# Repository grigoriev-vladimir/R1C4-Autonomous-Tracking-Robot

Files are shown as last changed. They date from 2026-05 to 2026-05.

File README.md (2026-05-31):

R1C4 - Autonomous Target Tracking Robot (Scale 3/5)

R1C4 is a 3/5 scale R2-D2 replica, co-developed as a duo with Emma Da Mota. It is equipped with computer vision to autonomously detect, track, and follow its "master" using a motorized turret system. This project combines computer vision, advanced mechatronics, and real-time control loops.

---

## 🎥 Demo
<table width="100%">
  <tr>
    <td width="50%" align="center">
      <p><b>Vision & Tracking (Jetson Nano)</b></p>
      <video src="https://github.com/user-attachments/assets/d546fa72-e5a3-4e6c-b071-dcd2d76cd6c8" width="100%" controls></video>
    </td>
    <td width="50%" align="center">
      <p><b>Comportement du Robot (Mechatronics)</b></p>
      <video src="https://github.com/user-attachments/assets/aad1944b-dfc9-40ba-a5d5-88d33bf9193e" width="100%" controls></video>
    </td>
  </tr>
</table>

---

## ✨ Key Features
* **Person Detection & Tracking:** Real-time human tracking using Computer Vision.
* **Active Turret Control:** Motorized dome/turret that smoothly pans to keep the target centered in the camera's field of view.
* **Custom Mechatronics:** Integrated power management, motor drivers, and 3/5 scale mechanical integration.

---

## 🛠️ Hardware Architecture
The robot architecture bridges high-level processing with low-level hardware actuation:

| Component Type | Model / Specification | Function |
| :--- | :--- | :--- |
| **Main Compute** | NVIDIA Jetson Nano | Runs the AI vision pipeline and processes the webcam feed |
| **Microcontroller** | ESP32 | Manages low-level motor control and timing |
| **Camera** |Logitech Webcam | Captures real-time video stream for tracking |
| **Turret Actuator** | Stepper Motor + TMC2209 | Drives the dome rotation smoothly and silently |
| **Wheel Actuator** | DC Motors + MDD10A SmartDrive | Controls the robot's main mobility and platform movement |
| **Power Supply** | External Power Bank / Battery | Provides independent power to the compute unit and motors |

---

## 🧠 Software & Control Logic

### 1. Vision & Recognition Pipeline
The high-level compute unit processes the webcam video feed frame-by-frame using a dual-stage approach:
* **Face Recognition (LBPH):** The system uses the **LBPH (Local Binary Patterns Histograms)** recognizer from OpenCV. It identifies the specific face of the "Master" based on a pre-trained dataset of face samples.
* **Target Tracking (CSRT):** Once the master is recognized, the system initializes an OpenCV **CSRT Tracker** on the target. This ensures robust, real-time tracking even with fast movements or partial occlusions.
* **Logic:** The Python script extracts the tracking bounding box center coordinates and calculates the horizontal pixel error relative to the camera's center view.

### 2. Communication & Control Loop
The tracking error is sent in real-time to the microcontroller to drive the robot's actuators:
* **Data Transmission:** The calculated pixel error is transmitted from the NVIDIA Jetson Nano to the **ESP32** via a **Serial (UART) link**.
* **Turret Actuation:** The ESP32 processes this error to command the **TMC2209** driver. It dynamically adjusts the stepper motor's speed and direction to smoothly and silently rotate the dome, keeping the master centered in the camera's field of view.
* **Mobility:** In parallel, the ESP32 handles the robot's displacement by driving the main DC motors through the **MDD10A** smart driver based on the system's operational state.
---

## 📁 Repository Structure
```text
├── src/
│   ├── vision/       # Python scripts for computer vision and target tracking
│   └── control/      # C++/Arduino firmware for motor control loops
├── hardware/
│   ├── electronics/  # Wiring diagrams and schematics
│   └── 3d-models/    # STL files for the custom turret mechanism
└── media/            # Images and GIFs for documentation

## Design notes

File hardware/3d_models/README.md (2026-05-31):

This folder contains the STL files for the custom parts of R1-C4 (dome mechanism, brackets, etc.)

Capture d'écran 2026-05-31 133051

## 🛠️ Bill of Materials (BOM) & Quantities

This section details the mechanical components and exact quantities required to build the robot assemblies, organized into three main modules.

### 🚗 1. Chassis Module (Requirements for 2 Full Chassis)
To manufacture **2 complete chassis**, the following mechanical parts are needed:
* **4x** Threaded rods (`R1C4-threaded_rod.step`) -> *4 threaded rods are strictly required to mount the wheels*
* **4x** Wheels (`R1C4-wheel.step`) -> *4 wheels are strictly required to assemble the chassis mechanism*
* **4x** Wheel covers with 13T pinion (`R1C4-wheel_cover_with_13t_pinion.step`)
* **2x** Chassis bases with motor (`R1C4-chassis_base_with_motor.step`)
* **2x** Chassis without motor (`R1C4-chassis_without_motor.step`)
* **2x** Motor pinions 22T (`R1C4-motor_pinion_22t.step`)
* **2x** Large support rods (`R1C4-arm_support_rod.step`)
* **6x** Mini rods (`R1C4-mini_rod.step`)
* **8x** Small nuts M12 (`R1C4-small_nut_m12_1_75.step`)
* **8x** Large nuts M12 (`R1C4-large_nut_m12_1_75_threaded_rod.step`)

---

### 🗼 2. Turret Module (Single Unit Requirements)
For the upper section and the tracking turret mechanism, only **1 unit** of each component is required:
* **1x** Dome / Capot (`R1C4-dome.step`)
* **1x** Turret skirt (`R1C4-turret_skirt.step`)
* **1x** Turret pinion (`R1C4-turret_pinion.step`)
* **1x** Motor pinion (`R1C4-motor_pinion_22t.step`)
* **1x** Top plate (`R1-C4 - Top.step`)
* **1x** Main Skirt (`R1-C4 - Skirt.step`)

---

### 🦴 3. Carcass Module (Structure & Frame - Single Unit Requirements)
All other structural components required to complete the main robot body (carcass) and internal mechanisms need **1 unit** each:
* **1x** R1-C4 - Chassis One Block.step
* **1x** Main Leg (`R1-C4 - Leg.step`)
* **1x** Ankle joint (`R1-C4 - Ankle.step`)
* **1x** Center foot axle (`R1-C4 - Axe center foot.step`)
* **1x** Elevator cage (`R1-C4 - Cage d'ascenseur V2.step`)
* **1x** Translation guide axle (`R1-C4 - Axe guide en translation.step`)
* **1x** Actuator support (`Support vérin V2.step`)
* **1x** Linear actuator lever arm (`R1C4-actuator_lever_arm.step`)
* **1x** Right wheel (`Roue droite.step`)
* **1x** Translation stop system (`R1-C4 - Arret en translation.step`)
* **1x** Upper translation stop bracket (`R1-C4 - Equerre arret translation haut.step`)
* **1x** Lower translation stop bracket (`R1-C4 - Equerre arret translation bas.step`)
* **1x** Motor support bracket (`R1-C4 - Equerre support moteur.step`)
* **1x** Translation guidance assembly (`R1-C4 - Assemblage guidage en translation...`)

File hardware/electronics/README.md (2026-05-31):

# ⚡ Electronics & Power Distribution

This folder contains the electrical architecture of R1-C4.

## 🗺️ Wiring Diagram

circuit diagram

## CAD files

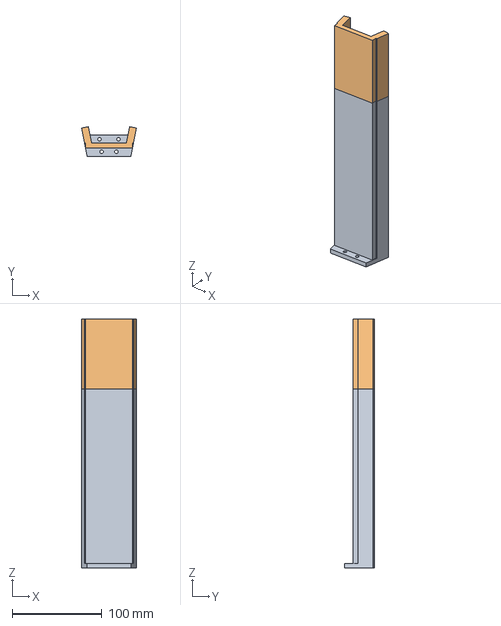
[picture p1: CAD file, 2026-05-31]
hardware/3d_models/R1-C4 - Assemblage guidage en translation front.step
61.2 x 33.0 x 278.0 mm

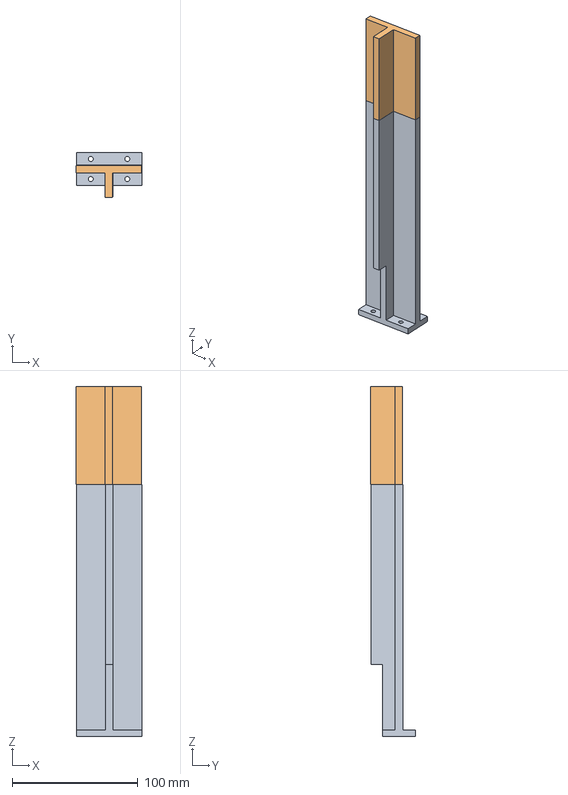
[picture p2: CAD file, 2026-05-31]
hardware/3d_models/R1C4-translation_guidance_assembly_02.step
52.1 x 35.5 x 278.0 mm

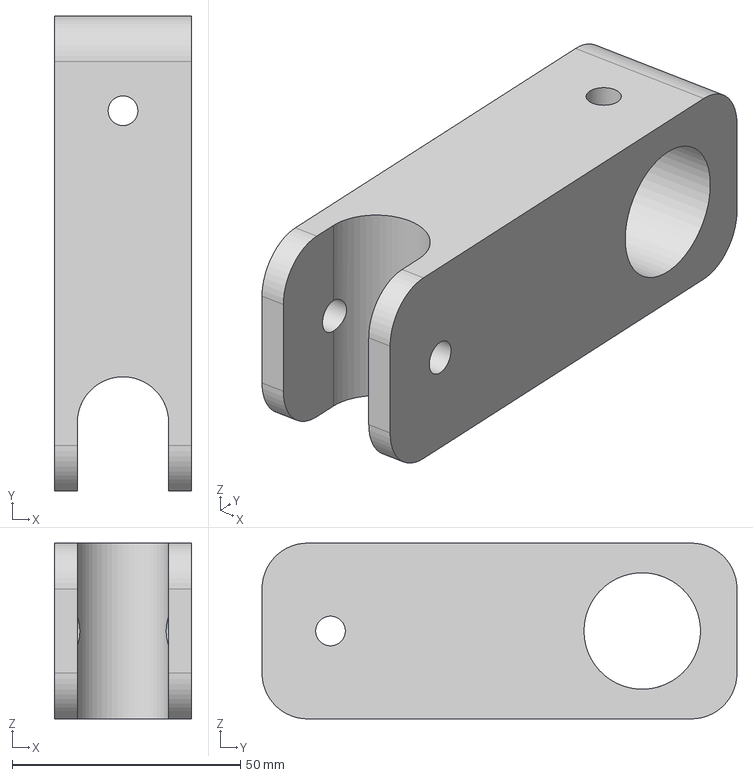
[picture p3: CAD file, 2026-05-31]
hardware/3d_models/R1C4-actuator_lever_arm.step
30.0 x 104.0 x 38.5 mm

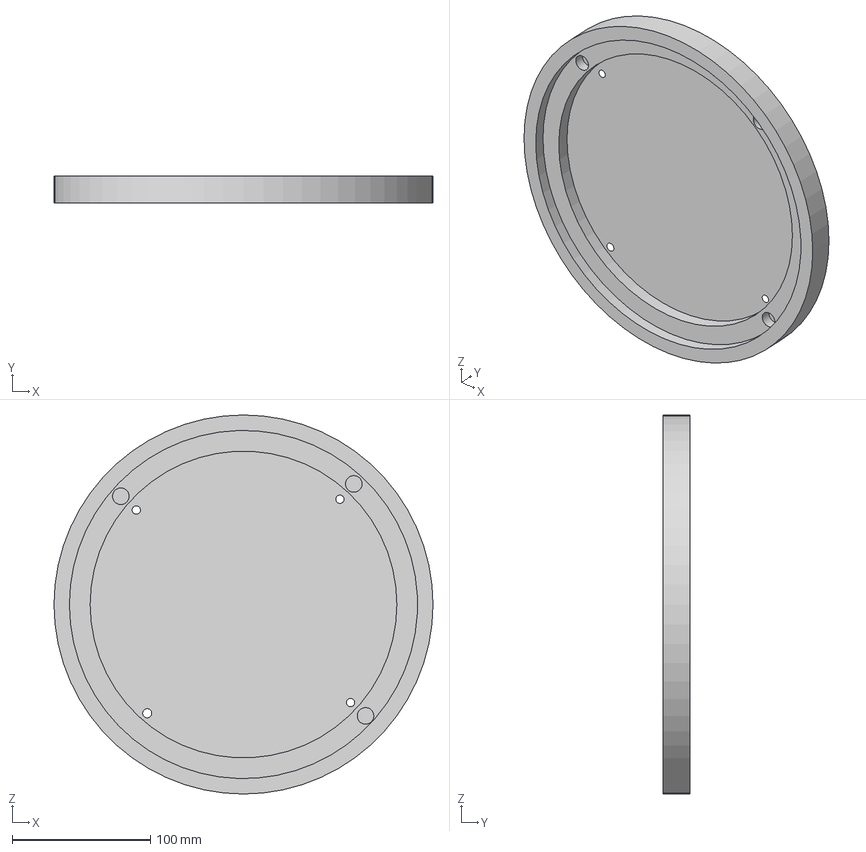
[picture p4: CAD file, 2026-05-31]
hardware/3d_models/R1C4-dome.step
274.3 x 19.8 x 274.3 mm

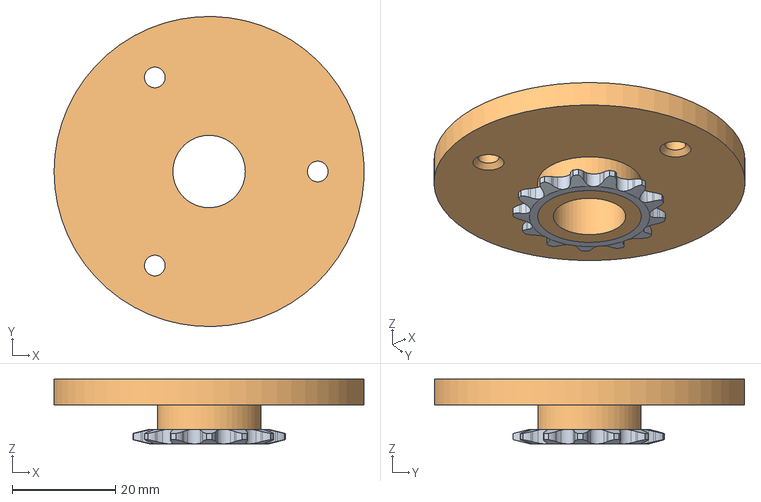
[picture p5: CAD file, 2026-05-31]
hardware/3d_models/R1C4-wheel_cover_with_13t_pinion.step
60.0 x 60.0 x 12.5 mm

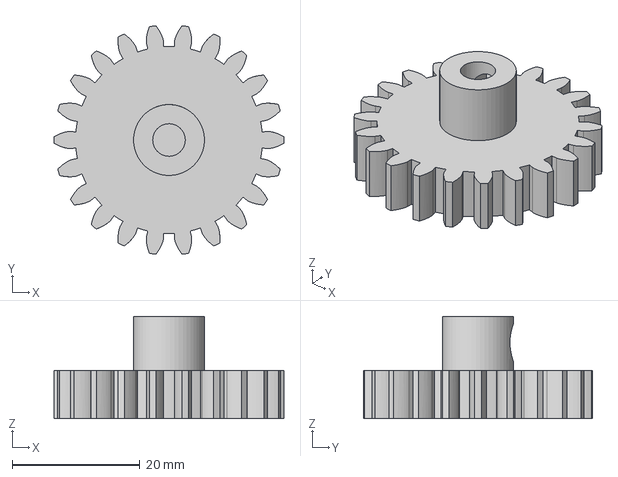
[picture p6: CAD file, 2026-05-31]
hardware/3d_models/R1C4-motor_pinion_22t.step
36.0 x 35.8 x 16.0 mm

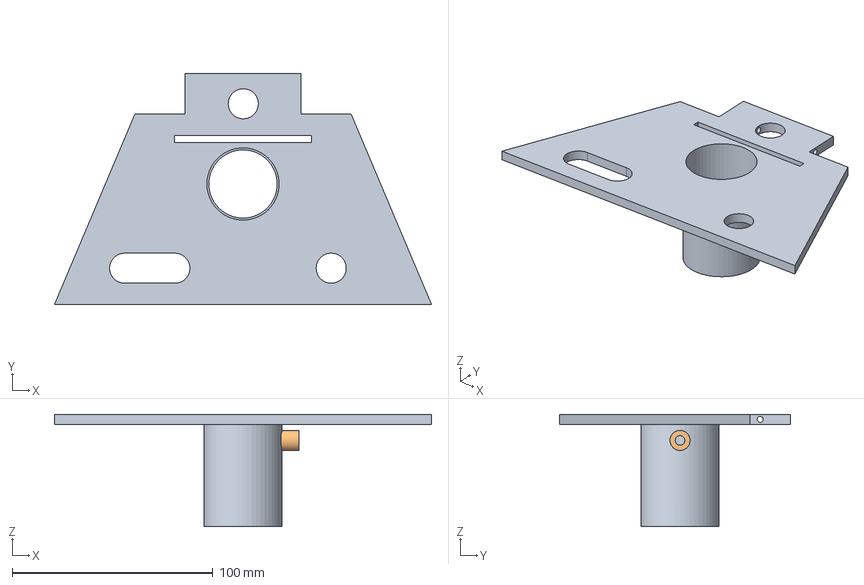
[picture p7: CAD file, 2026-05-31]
hardware/3d_models/R1C4-chassis_base_with_motor.step
188.0 x 115.0 x 56.0 mm

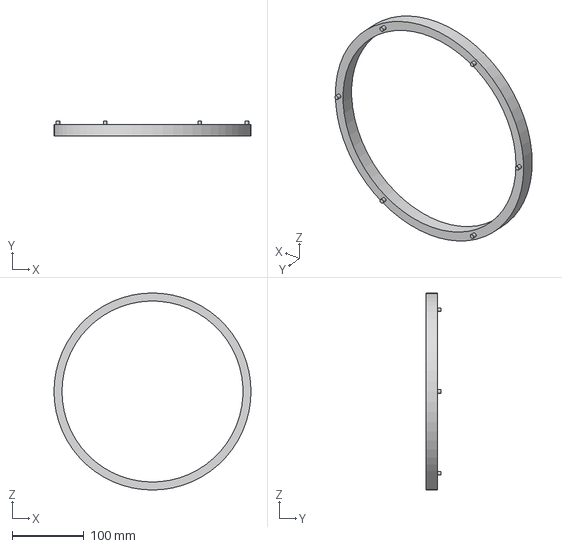
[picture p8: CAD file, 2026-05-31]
hardware/3d_models/R1C4-turret_skirt.step
274.3 x 21.0 x 274.3 mm

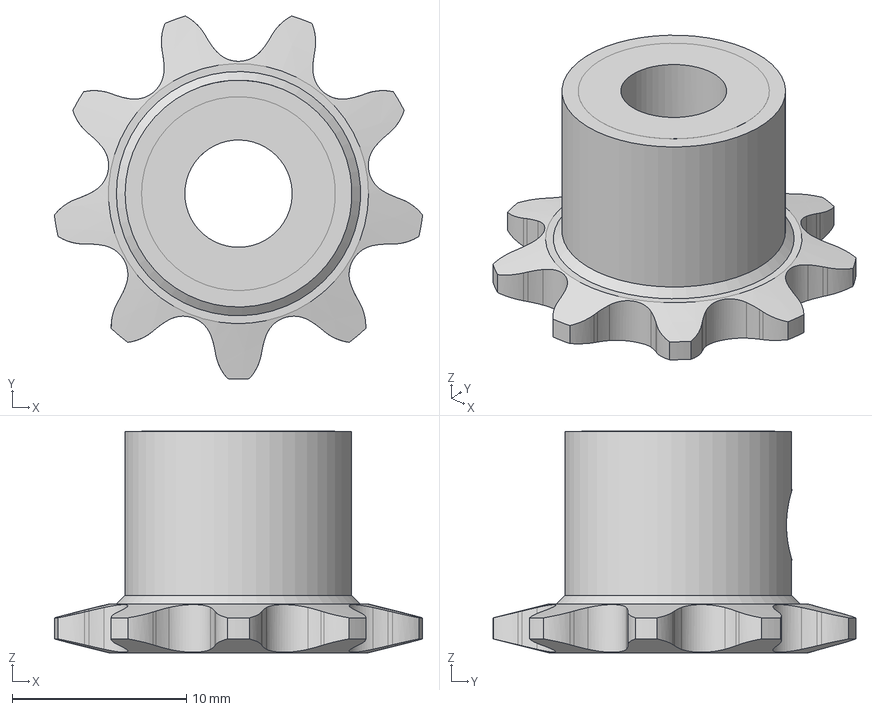
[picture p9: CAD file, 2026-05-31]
hardware/3d_models/R1C4-sprocket_9t_chain_25h_improved.step
21.1 x 20.8 x 12.7 mm

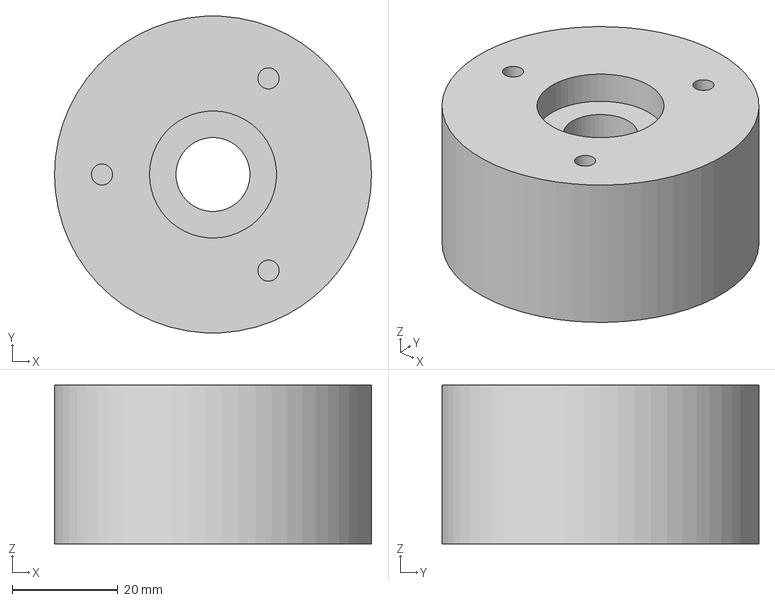
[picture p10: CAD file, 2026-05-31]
hardware/3d_models/R1C4-wheel.step
60.0 x 59.9 x 30.0 mm

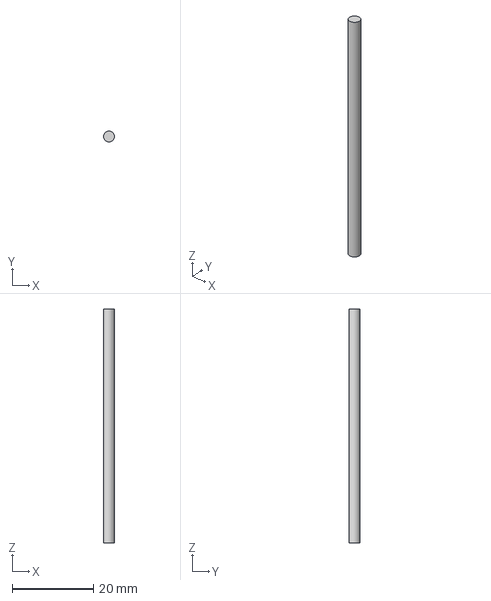
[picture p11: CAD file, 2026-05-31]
hardware/3d_models/R1C4-mini_rod.step
2.70 x 2.70 x 57.7 mm

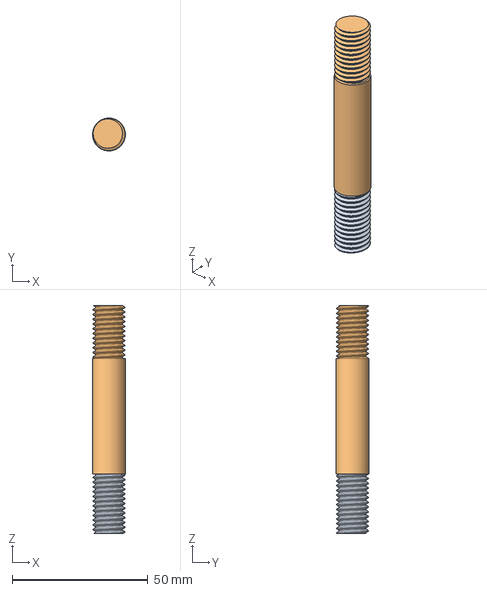
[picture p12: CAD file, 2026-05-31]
hardware/3d_models/R1C4-threaded_rod.step
12.1 x 12.1 x 84.1 mm

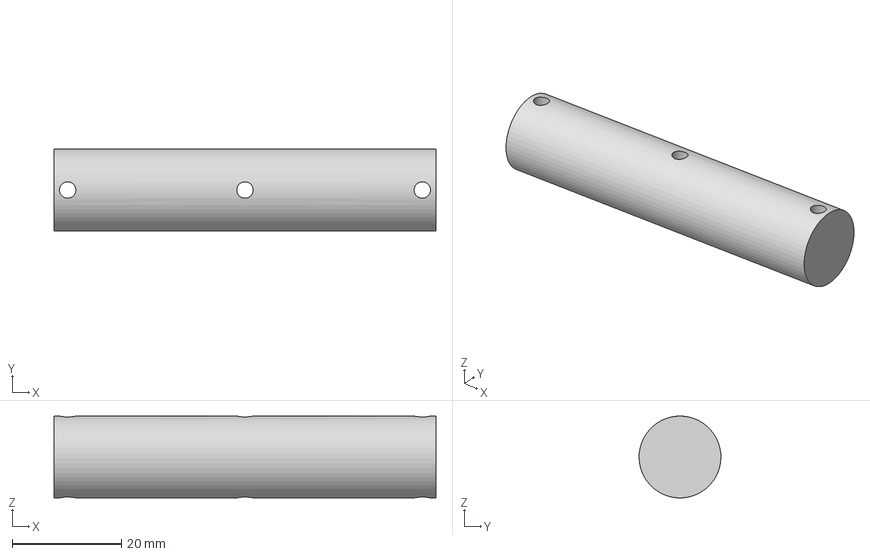
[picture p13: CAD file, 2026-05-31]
hardware/3d_models/R1C4-arm_support_rod.step
70.0 x 15.0 x 15.0 mm

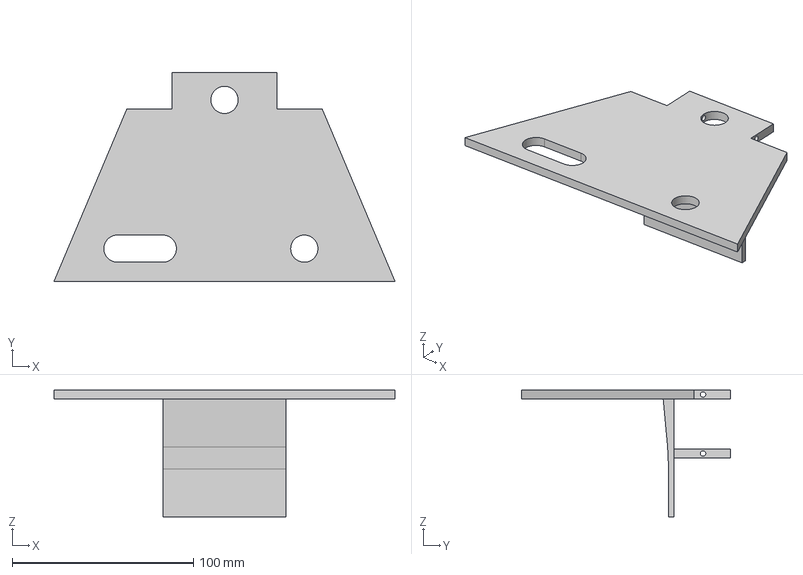
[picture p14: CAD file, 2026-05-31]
hardware/3d_models/R1C4-chassis_without_motor.step
188.0 x 115.0 x 70.0 mm

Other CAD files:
hardware/3d_models/R1-C4 - Equerre arret translation bas.step
hardware/3d_models/R1C4-translation_stop.step
hardware/3d_models/R1-C4 - Equerre support moteur.step
hardware/3d_models/R1-C4 - Equerre arret translation haut.step
hardware/3d_models/R1-C4 - Ankle.step
hardware/3d_models/R1-C4 - Axe center foot.step
hardware/3d_models/R1-C4 - Axe guide en translation.step
hardware/3d_models/R1-C4 - Cage d'ascenseur V2.step
hardware/3d_models/R1-C4 - Leg.step
hardware/3d_models/R1C4-large_nut_m12_1_75_threaded_rod.step
hardware/3d_models/R1C4-right_wheel.step
hardware/3d_models/R1C4-small_nut_m12_1_75.step

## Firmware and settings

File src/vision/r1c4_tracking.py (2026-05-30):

import json
import threading
import time
from pathlib import Path

import cv2
import numpy as np
import serial

# ══════════════════════════════════════════════════════════════════════════════
# ARRÊT PROPRE PAR "stop" DANS LE TERMINAL
# ══════════════════════════════════════════════════════════════════════════════
stop_event = threading.Event()

def _keyboard_listener():
    """Thread qui écoute le terminal : tape 'stop' + Entrée pour arrêter."""
    while not stop_event.is_set():
        try:
            line = input()
            if line.strip().lower() == "stop":
                print("Commande STOP reçue — arrêt en cours...")
                stop_event.set()
        except EOFError:
            break

_kb_thread = threading.Thread(target=_keyboard_listener, daemon=True)
_kb_thread.start()

# ══════════════════════════════════════════════════════════════════════════════
# CONFIGURATION
# ══════════════════════════════════════════════════════════════════════════════
PORT        = "COM3"        # ← votre port ESP32
BAUD        = 115200
SANS_SERIE  = False         # True = test sans ESP32

CAM_INDEX   = 1
# Résolution NATIVE de la caméra (avant rotation)
CAM_W       = 640
CAM_H       = 480
# Après rotation 90° : largeur et hauteur s'inversent
FRAME_W     = CAM_H        # = 480
FRAME_H     = CAM_W        # = 640

MODEL_PATH  = Path("lbph_model.yml")
LABELS_PATH = Path("labels.json")

FACE_SIZE   = (200, 200)
MIN_FACE    = (80, 80)
THRESHOLD   = 75.0        # distance LBPH max — ajustez selon vos distances
TRACK_FACE_THRESHOLD = 125.0   # plus tolérant pendant le suivi, utile profil/dos

# Tourelle
DEAD_ZONE_PX  = 50          # zone morte large → ignore les petits écarts
DEG_PER_PX    = 0.1        # gain très doux
MAX_ROT_DEG   = 15.0        # amplitude max réduite
ROT_PERIOD_S  = 0.25        # commande toutes les 250ms max

# Balayage recherche
SCAN_STEP_DEG  = 10
SCAN_LIMIT_DEG = 180
SCAN_PERIOD_S  = 1.8

# Tracker
TRACKER_LOST_LIMIT = 45

# Validation forme personne pour éviter de tracker le mur
MIN_PERSON_RATIO = 0.60   # hauteur / largeur minimale
MAX_PERSON_RATIO = 8.00   # hauteur / largeur maximale
MIN_BODY_AREA    = 1200   # surface min de la boîte


# ══════════════════════════════════════════════════════════════════════════════
# FILTRE DE KALMAN
# ══════════════════════════════════════════════════════════════════════════════
def make_kalman() -> cv2.KalmanFilter:
    kf = cv2.KalmanFilter(4, 2)
    dt = 1.0
    kf.transitionMatrix = np.array(
        [[1, 0, dt, 0],
         [0, 1,  0, dt],
         [0, 0,  1,  0],
         [0, 0,  0,  1]], dtype=np.float32)
    kf.measurementMatrix = np.array(
        [[1, 0, 0, 0],
         [0, 1, 0, 0]], dtype=np.float32)
    kf.processNoiseCov     = np.eye(4, dtype=np.float32) * 5e-3
    kf.measurementNoiseCov = np.eye(2, dtype=np.float32) * 5e-2
    kf.errorCovPost        = np.eye(4, dtype=np.float32)
    return kf


def kalman_get_xy(matrix) -> tuple:
    """Extrait (x, y) depuis la matrice état Kalman (4x1) en toute sécurité."""
    return int(matrix[0][0]), int(matrix[1][0])


# ══════════════════════════════════════════════════════════════════════════════
# COMMUNICATION SÉRIE
# ══════════════════════════════════════════════════════════════════════════════
def wait_for_done(ser, timeout_s=8.0) -> str:
    if ser is None:
        return "DONE"
    start = time.time()
    while time.time() - start < timeout_s:
        if ser.in_waiting:
            line = ser.readline().decode(errors="ignore").strip()
            if line:
                print("Carte ->", line)
                if line == "DONE":
                    return line
        time.sleep(0.05)
    return ""


def send_rot(ser, deg: float):
    if ser is None:
        return

    deg = max(-MAX_ROT_DEG, min(MAX_ROT_DEG, deg))
    ideg = int(round(deg))

    if ideg == 0:
        return

    sign = "+" if ideg >= 0 else "-"
    cmd = f"ROT:{sign}{abs(ideg):03d}\n"
    print("PC ->", cmd.strip())
    ser.write(cmd.encode())
    ser.flush()


def send_buzzer(ser, duration_ms: int = 800):
    """Déclenche le buzzer de l'ESP32 pour signaler une perte de cible."""
    if ser is None:
        print("[BUZZER] bip simulé (pas de série)")
        return
    cmd = f"BUZ:{duration_ms:04d}\n"
    print("PC ->", cmd.strip())
    ser.write(cmd.encode())
    ser.flush()

# ══════════════════════════════════════════════════════════════════════════════
# CHARGEMENT RESSOURCES
# ══════════════════════════════════════════════════════════════════════════════
def load_labels(path: Path) -> dict:
    data = json.loads(path.read_text(encoding="utf-8"))
    return {int(v): k for k, v in data["name_to_id"].items()}


def load_cascade() -> cv2.CascadeClassifier:
    p = cv2.data.haarcascades + "haarcascade_frontalface_default.xml"
    c = cv2.CascadeClassifier(p)
    if c.empty():
        raise RuntimeError("Haar cascade introuvable")
    return c


def preprocess_face(bgr_roi: np.ndarray) -> np.ndarray:
    gray = cv2.cvtColor(bgr_roi, cv2.COLOR_BGR2GRAY)
    gray = cv2.resize(gray, FACE_SIZE, interpolation=cv2.INTER_AREA)
    return cv2.equalizeHist(gray)


def face_to_body_box(x, y, w, h, frame_h, frame_w=None) -> tuple:
    """
    Boîte de suivi agrandie : tête + torse + bras.
    Elle reste centrée sur toi, mais évite de prendre trop de mur.
    """
    margin_x = int(w * 1.05)
    body_h   = int(h * 4.3)

    bx = max(0, x - margin_x)
    by = max(0, y - int(h * 0.25))
    bw = w + 2 * margin_x
    bh = min(body_h, frame_h - by)

    if frame_w is not None:
        bw = min(bw, frame_w - bx)

    return (int(bx), int(by), int(bw), int(bh))


# ══════════════════════════════════════════════════════════════════════════════
# ÉTAT PARTAGÉ ENTRE THREADS
# ══════════════════════════════════════════════════════════════════════════════
class SharedState:
    def __init__(self):
        self.lock = threading.Lock()
        self.phase         = "SEARCH"   # "SEARCH" | "TRACK" | "RELOCK"
        self.det_name      = ""
        self.det_dist      = 999.0
        self.face_box      = None       # (x,y,w,h) visage reconnu
        self.body_box      = None       # (x,y,w,h) corps HOG
        self.recognized    = False      # visage reconnu ce cycle
        self.frame         = None
        self.stop          = False


# ══════════════════════════════════════════════════════════════════════════════
# THREAD DÉTECTION (arrière-plan, ~12 Hz)
# ══════════════════════════════════════════════════════════════════════════════
def detection_thread(state: SharedState, recognizer, cascade, hog, id_to_name):
    while not state.stop:
        with state.lock:
            if state.frame is None:
                pass
            else:
                frame = state.frame.copy()
                phase = state.phase

        time.sleep(0.08)

        with state.lock:
            if state.frame is None:
                continue
            frame = state.frame.copy()
            phase = state.phase

        gray = cv2.cvtColor(frame, cv2.COLOR_BGR2GRAY)

        if phase == "SEARCH":
            faces = cascade.detectMultiScale(
                gray, scaleFactor=1.1, minNeighbors=5, minSize=MIN_FACE)

            recognized = False
            for (x, y, w, h) in faces:
                roi      = frame[y:y+h, x:x+w]
                face_img = preprocess_face(roi)
                lid, dist = recognizer.predict(face_img)
                name = id_to_name.get(lid, f"ID:{lid}")
                print(f"[DET] {name}  dist={dist:.1f}")

                with state.lock:
                    state.det_name = name
                    state.det_dist = dist

                if dist <= THRESHOLD:
                    # Chercher corps HOG
                    body = _find_body_hog(hog, frame)
                    if body is None:
                        # Pas de corps HOG → estimer depuis le visage
                        body = face_to_body_box(x, y, w, h, frame.shape[0], frame.shape[1])

                    with state.lock:
                        state.recognized = True
                        state.face_box   = (x, y, w, h)
                        state.body_box   = body
                    recognized = True
                    break

            if not recognized:
                with state.lock:
                    state.recognized = False

        elif phase == "RELOCK":
            # Phase RELOCK : on cherche TON visage spécifiquement (LBPH strict)
            faces = cascade.detectMultiScale(
                gray, scaleFactor=1.1, minNeighbors=5, minSize=MIN_FACE)

            recognized = False
            for (x, y, w, h) in faces:
                roi      = frame[y:y+h, x:x+w]
                face_img = preprocess_face(roi)
                lid, dist = recognizer.predict(face_img)
                name = id_to_name.get(lid, f"ID:{lid}")
                print(f"[RELOCK] {name}  dist={dist:.1f}")

                with state.lock:
                    state.det_name = name
                    state.det_dist = dist

                if dist <= THRESHOLD:
                    body = _find_body_hog(hog, frame)
                    if body is None:
                        body = face_to_body_box(x, y, w, h, frame.shape[0], frame.shape[1])

                    with state.lock:
                        state.recognized = True
                        state.face_box   = (x, y, w, h)
                        state.body_box   = body
                    recognized = True
                    break

            if not recognized:
                with state.lock:
                    state.recognized = False

        else:
            # Phase TRACK : recalage par visage reconnu, pas par HOG.
            faces = cascade.detectMultiScale(
                gray, scaleFactor=1.1, minNeighbors=5, minSize=MIN_FACE)

            for (x, y, w, h) in faces:
                roi = frame[y:y+h, x:x+w]
                face_img = preprocess_face(roi)
                lid, dist = recognizer.predict(face_img)

                if dist <= TRACK_FACE_THRESHOLD:
                    body = face_to_body_box(x, y, w, h, frame.shape[0], frame.shape[1])
                    with state.lock:
                        state.body_box = body
                    break


def _find_body_hog(hog, frame):
    return find_body_near_tracker(hog, frame, None)



def is_person_like_box(box, frame_shape) -> bool:
    """
    Filtre permissif : refuse seulement les boîtes absurdes.
    Avant c'était trop strict, donc ça affichait souvent "pas assez personne".
    """
    if box is None:
        return False

    x, y, w, h = [int(v) for v in box]
    if w <= 0 or h <= 0:
        return False

    frame_h, frame_w = frame_shape[:2]
    area = w * h

    if area < 1200:
        return False

    if w > frame_w * 0.95 or h > frame_h * 0.98:
        return False

    if w < 15 or h < 25:
        return False

    return True



def box_center(box):
    x, y, w, h = [int(v) for v in box]
    return x + w // 2, y + h // 2


def find_body_near_tracker(hog, frame, previous_box=None):
    """
    Cherche une silhouette humaine avec HOG, mais refuse les boîtes absurdes.
    Si on a une position précédente, on prend la détection proche de l'ancien centre.
    """
    rects, _ = hog.detectMultiScale(
        frame, winStride=(8, 8), padding=(4, 4), scale=1.05,
        useMeanshiftGrouping=True)

    candidates = []
    for r in rects:
        box = tuple(int(v) for v in r)
        if is_person_like_box(box, frame.shape):
            candidates.append(box)

    if not candidates:
        return None

    if previous_box is None:
        # Si aucune ancienne position : plus grande boîte personne valide
        return max(candidates, key=lambda b: b[2] * b[3])

    pcx, pcy = box_center(previous_box)

    def score(b):
        cx, cy = box_center(b)
        dist2 = (cx - pcx) ** 2 + (cy - pcy) ** 2
        area = b[2] * b[3]
        # proche de l'ancien tracker + surface correcte
        return dist2 - area * 0.15

    return min(candidates, key=score)


# ══════════════════════════════════════════════════════════════════════════════
# PROGRAMME PRINCIPAL
# ══════════════════════════════════════════════════════════════════════════════
def main():

    # ── Série ─────────────────────────────────────────────────────────────────
    ser = None
    if not SANS_SERIE:
        ser = serial.Serial(PORT, BAUD, timeout=1)
        time.sleep(3)
        ser.reset_input_buffer()
        ser.reset_output_buffer()
        print(f"Série ouverte sur {PORT}")
    else:
        print("MODE SANS SERIE")

    # ── Chargement ────────────────────────────────────────────────────────────
    id_to_name = load_labels(LABELS_PATH)
    recognizer = cv2.face.LBPHFaceRecognizer_create()
    recognizer.read(str(MODEL_PATH))
    cascade    = load_cascade()
    hog        = cv2.HOGDescriptor()
    hog.setSVMDetector(cv2.HOGDescriptor_getDefaultPeopleDetector())

    # ── Caméra ────────────────────────────────────────────────────────────────
    cap = cv2.VideoCapture(CAM_INDEX, cv2.CAP_DSHOW)
    cap.set(cv2.CAP_PROP_BUFFERSIZE, 1)   # réduit la latence
    cap.set(cv2.CAP_PROP_FRAME_WIDTH,  CAM_W)
    cap.set(cv2.CAP_PROP_FRAME_HEIGHT, CAM_H)
    if not cap.isOpened():
        raise RuntimeError(f"Impossible d'ouvrir la caméra {CAM_INDEX}")

    # Laisser le temps à la caméra de s'initialiser
    time.sleep(1.0)
    for _ in range(10):
        cap.read()  # vider les premières frames noires

    # Centre horizontal après rotation
    cx = FRAME_W // 2   # = 240 (sur 480px de large après rotation)

    # ── Kalman ────────────────────────────────────────────────────────────────
    kf          = make_kalman()
    kalman_init = False

    # ── Tracker CSRT ──────────────────────────────────────────────────────────
    tracker      = None
    tracker_lost = 0
    previous_good_box = None

    # ── Thread détection ──────────────────────────────────────────────────────
    state = SharedState()
    det_t = threading.Thread(
        target=detection_thread,
        args=(state, recognizer, cascade, hog, id_to_name),
        daemon=True)
    det_t.start()

    # ── Variables tourelle ────────────────────────────────────────────────────
    scan_angle  = 0.0
    scan_dir    = +1
    last_scan_t = time.time() - SCAN_PERIOD_S
    last_rot_t  = time.time() - ROT_PERIOD_S
    err_history = []   # historique des erreurs pour lissage

    print(f"Démarrage RECHERCHE | seuil={THRESHOLD} | cam={CAM_INDEX} | cx={cx}")

    try:
        while not stop_event.is_set():
            ok, frame = cap.read()
            if not ok:
                break

            # ── Rotation 90° ──────────────────────────────────────────────────────
            # Changez en ROTATE_90_COUNTERCLOCKWISE si l'image est à l'envers
            frame = cv2.rotate(frame, cv2.ROTATE_90_COUNTERCLOCKWISE )

            # Mettre à jour la frame partagée
            with state.lock:
                state.frame = frame.copy()

            # Lire l'état partagé
            with state.lock:
                phase      = state.phase
                recognized = state.recognized
                body_box   = state.body_box
                det_name   = state.det_name
                det_dist   = state.det_dist

            now = time.time()

            # ══════════════════════════════════════════════════════════════════════
            # PHASE RECHERCHE
            # ══════════════════════════════════════════════════════════════════════
            if phase == "SEARCH":
                tracker      = None
                kalman_init  = False
                tracker_lost = 0

                cv2.putText(frame, f"TH={THRESHOLD:.0f}", (10, 25),
                            cv2.FONT_HERSHEY_SIMPLEX, 0.7, (255,255,255), 2)
                label = f"{det_name} dist={det_dist:.1f}" if det_name else "Aucun visage"
                cv2.putText(frame, label, (10, 55),
                            cv2.FONT_HERSHEY_SIMPLEX, 0.7, (255,255,255), 2)

                # ── Visage reconnu → passage en TRACK ───────────────────────────
                if recognized:
                    # Initialiser le tracker sur le corps (ou visage élargi)
                    with state.lock:
                        bb = state.body_box
                        state.recognized = False   # consommer le flag

                    if bb is not None:
                        tracker = cv2.TrackerCSRT_create()
                        tracker.init(frame, bb)
                        previous_good_box = bb
                        print(f"Tracker initialisé sur corps {bb}")
                    else:
                        print("Pas de box corps disponible — attente frame suivante")

                    with state.lock:
                        state.phase = "TRACK"

                # ── Balayage ─────────────────────────────────────────────────────
                elif not recognized and now - last_scan_t >= SCAN_PERIOD_S:
                    last_scan_t = now
                    next_a = scan_angle + scan_dir * SCAN_STEP_DEG
                    if abs(next_a) >= SCAN_LIMIT_DEG:
                        scan_dir *= -1
                        next_a = scan_angle + scan_dir * SCAN_STEP_DEG
                    delta      = next_a - scan_angle
                    scan_angle = next_a
                    send_rot(ser, delta)

                cv2.putText(frame, f"Scan {scan_angle:+.0f}deg", (10, 85),
                            cv2.FONT_HERSHEY_SIMPLEX, 0.6, (180,180,180), 1)

            # ══════════════════════════════════════════════════════════════════════
            # PHASE RELOCK — perdu pendant le suivi → re-identification LBPH
            # ══════════════════════════════════════════════════════════════════════
            elif phase == "RELOCK":
                tracker      = None
                kalman_init  = False
                tracker_lost = 0

                # Fond rouge clignotant pour signaler la perte
                blink = int(now * 3) % 2 == 0
                color_alert = (0, 0, 220) if blink else (0, 0, 100)
                cv2.rectangle(frame, (0, 0), (FRAME_W, FRAME_H), color_alert, 4)

                cv2.putText(frame, "!! CIBLE PERDUE !!", (10, 30),
                            cv2.FONT_HERSHEY_SIMPLEX, 0.85, (0, 0, 255), 3)
                cv2.putText(frame, "Refais face a la camera", (10, 65),
                            cv2.FONT_HERSHEY_SIMPLEX, 0.65, (0, 100, 255), 2)
                label = f"{det_name} dist={det_dist:.1f}" if det_name else "En attente..."
                cv2.putText(frame, label, (10, 100),
                            cv2.FONT_HERSHEY_SIMPLEX, 0.65, (255, 200, 0), 2)

                if recognized:
                    with state.lock:
                        bb = state.body_box
                        state.recognized = False

                    if bb is not None:
                        tracker = cv2.TrackerCSRT_create()
                        tracker.init(frame, bb)
                        previous_good_box = bb
                        print(f"[RELOCK] Visage retrouvé — tracker recalé sur {bb}")
                    else:
                        print("[RELOCK] Visage reconnu mais pas de box corps — attente")

                    with state.lock:
                        state.phase = "TRACK"

            # ══════════════════════════════════════════════════════════════════════
            # PHASE SUIVI
            # ══════════════════════════════════════════════════════════════════════
            elif phase == "TRACK":
                # Recalage seulement si la boîte ressemble à une personne
                # ET que c'est bien toi (vérification LBPH dans la boîte)
                if body_box is not None and (tracker is None or tracker_lost > 8):
                    if is_person_like_box(body_box, frame.shape):
                        bx, by, bw, bh = [int(v) for v in body_box]
                        roi = frame[by:by+bh, bx:bx+bw]
                        gray_roi = cv2.cvtColor(roi, cv2.COLOR_BGR2GRAY)
                        faces_in_box = cascade.detectMultiScale(
                            gray_roi, scaleFactor=1.1, minNeighbors=4,
                            minSize=(40, 40))
                        good_person = False
                        for (fx, fy, fw, fh) in faces_in_box:
                            face_img = preprocess_face(roi[fy:fy+fh, fx:fx+fw])
                            lid, dist = recognizer.predict(face_img)
                            if dist <= TRACK_FACE_THRESHOLD:
                                good_person = True
                                break
                        if good_person or tracker is None or tracker_lost > 20:
                            tracker = cv2.TrackerCSRT_create()
                            tracker.init(frame, body_box)
                            previous_good_box = body_box
                            kalman_init  = False
                            tracker_lost = 0
                            print(f"Tracker recalé sur personne {body_box}")
                    else:
                        print(f"Boîte refusée absurde: {body_box}")

                    with state.lock:
                        state.body_box = None

                tracked_ok = False

                if tracker is not None:
                    ok_t, bbox = tracker.update(frame)

                    if ok_t:
                        tx, ty, tw, th = [int(v) for v in bbox]
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

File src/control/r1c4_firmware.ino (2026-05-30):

/*
  ESP32 Tourelle - rotation + buzzer actif
  - ROT:+010 / ROT:-010 : rotation tourelle
  - BUZ:0800             : buzzer pendant N ms (perte de cible)

  Buzzer actif rond noir 2 pattes :
    + (patte longue) → GPIO 22
    - (patte courte) → GND
*/

#include <Arduino.h>
#include <math.h>

#define PIN_STEP   18
#define PIN_DIR    19
#define PIN_EN     21
#define PIN_BUZZER 22

#define QUEUE_SIZE    20
#define STEPS_PER_DEG 8.8889
#define STEP_DELAY_US 400

const bool INVERT_DIR = false;

QueueHandle_t rotQueue;
QueueHandle_t buzQueue;

void buzzerBeep(int duration_ms) {
  digitalWrite(PIN_BUZZER, HIGH);
  delay(duration_ms);
  digitalWrite(PIN_BUZZER, LOW);
}

void stepMotorDegrees(float deg) {
  if (deg == 0.0 || isnan(deg)) return;

  bool dir = deg >= 0;
  if (INVERT_DIR) dir = !dir;

  digitalWrite(PIN_DIR, dir ? HIGH : LOW);

  int steps = abs((int)round(deg * STEPS_PER_DEG));
  if (steps <= 0) return;

  int ramp = min(steps / 2, 15);

  for (int i = 0; i < steps; i++) {
    int delay_us;
    if (i < ramp) {
      delay_us = STEP_DELAY_US + (ramp - i) * 80;
    } else if (i >= steps - ramp) {
      delay_us = STEP_DELAY_US + (i - (steps - ramp)) * 80;
    } else {
      delay_us = STEP_DELAY_US;
    }

    digitalWrite(PIN_STEP, HIGH);
    delayMicroseconds(delay_us);
    digitalWrite(PIN_STEP, LOW);
    delayMicroseconds(delay_us);
  }
}

void taskSerialCom(void* param) {
  String cmd;

  while (true) {
    if (Serial.available()) {
      cmd = Serial.readStringUntil('\n');
      cmd.trim();

      if (cmd.length() == 0) {
        vTaskDelay(2 / portTICK_PERIOD_MS);
        continue;
      }

      if (cmd.startsWith("ROT:")) {
        float deg = cmd.substring(4).toFloat();
        xQueueSend(rotQueue, &deg, 0);
      } else if (cmd.startsWith("BUZ:")) {
        int dur = cmd.substring(4).toInt();
        if (dur > 0 && dur <= 5000) {
          xQueueSend(buzQueue, &dur, 0);
        }
      }
    }

    vTaskDelay(2 / portTICK_PERIOD_MS);
  }
}

void taskMoteur(void* param) {
  while (true) {
    float deg;
    if (xQueueReceive(rotQueue, &deg, portMAX_DELAY) == pdTRUE) {
      stepMotorDegrees(deg);
    }
  }
}

void taskBuzzer(void* param) {
  while (true) {
    int dur;
    if (xQueueReceive(buzQueue, &dur, portMAX_DELAY) == pdTRUE) {
      buzzerBeep(dur);
    }
  }
}

void setup() {
  Serial.begin(115200);

  pinMode(PIN_STEP,   OUTPUT);
  pinMode(PIN_DIR,    OUTPUT);
  pinMode(PIN_EN,     OUTPUT);
  pinMode(PIN_BUZZER, OUTPUT);

  digitalWrite(PIN_EN,     LOW);
  digitalWrite(PIN_STEP,   LOW);
  digitalWrite(PIN_DIR,    LOW);
  digitalWrite(PIN_BUZZER, LOW);

  rotQueue = xQueueCreate(QUEUE_SIZE, sizeof(float));
  buzQueue = xQueueCreate(4,          sizeof(int));

  xTaskCreatePinnedToCore(taskSerialCom, "SerialCom", 4096, NULL, 1, NULL, 0);
  xTaskCreatePinnedToCore(taskMoteur,    "Moteur",    4096, NULL, 2, NULL, 1);
  xTaskCreatePinnedToCore(taskBuzzer,    "Buzzer",    2048, NULL, 1, NULL, 0);

  Serial.println("READY");
}

void loop() {
  vTaskDelay(1000 / portTICK_PERIOD_MS);
}

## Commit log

2026-05-31 Rename Roue droite.step to R1C4-right_wheel.step
    [R1C4-right_wheel.step]
2026-05-31 Rename R1-C4 - Arret en translation.step to R1C4-translation_stop.step
    [R1C4-translation_stop.step]
2026-05-31 Rename R1-C4 - Assemblage guidage en translation back.step to R1C4-translation_guidance_assembly_02.step
    [R1C4-translation_guidance_assembly_02.step]
